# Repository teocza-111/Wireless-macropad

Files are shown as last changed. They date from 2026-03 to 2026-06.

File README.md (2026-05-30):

# Wireless-macropad
It's a basic 3x3 keyboard with bluetooth connectivity and a rotary encoder built on ZMK firmware.
## Quick note for forge reviewers:
This project was fully funded by stasis I'm moving this here since I plan to make my future projects on forge 
## It features a(n):
- nrf52840 microcontroller
- Seeed 106990290 lipo charger
- EC11E Rotary Encoder w/ switch
- Li-Po Battery 4000mah
### Why?
I like simracing but i needed some extra keybinds so i made my first vesion of this project but it was annoying that there was an extra cable on my desk so now im making it wireless.
# Media
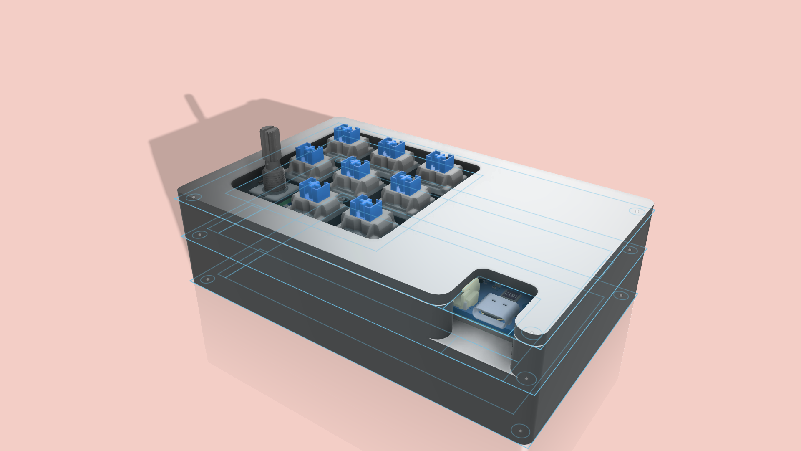
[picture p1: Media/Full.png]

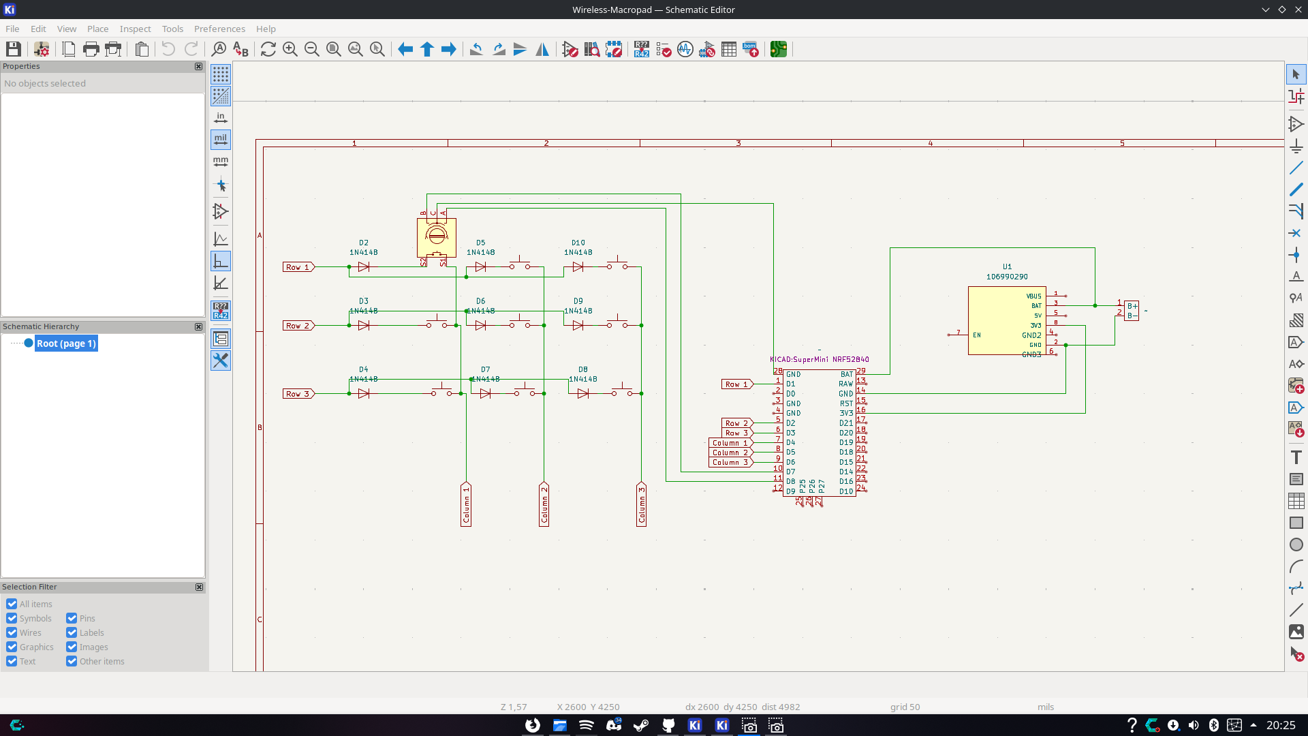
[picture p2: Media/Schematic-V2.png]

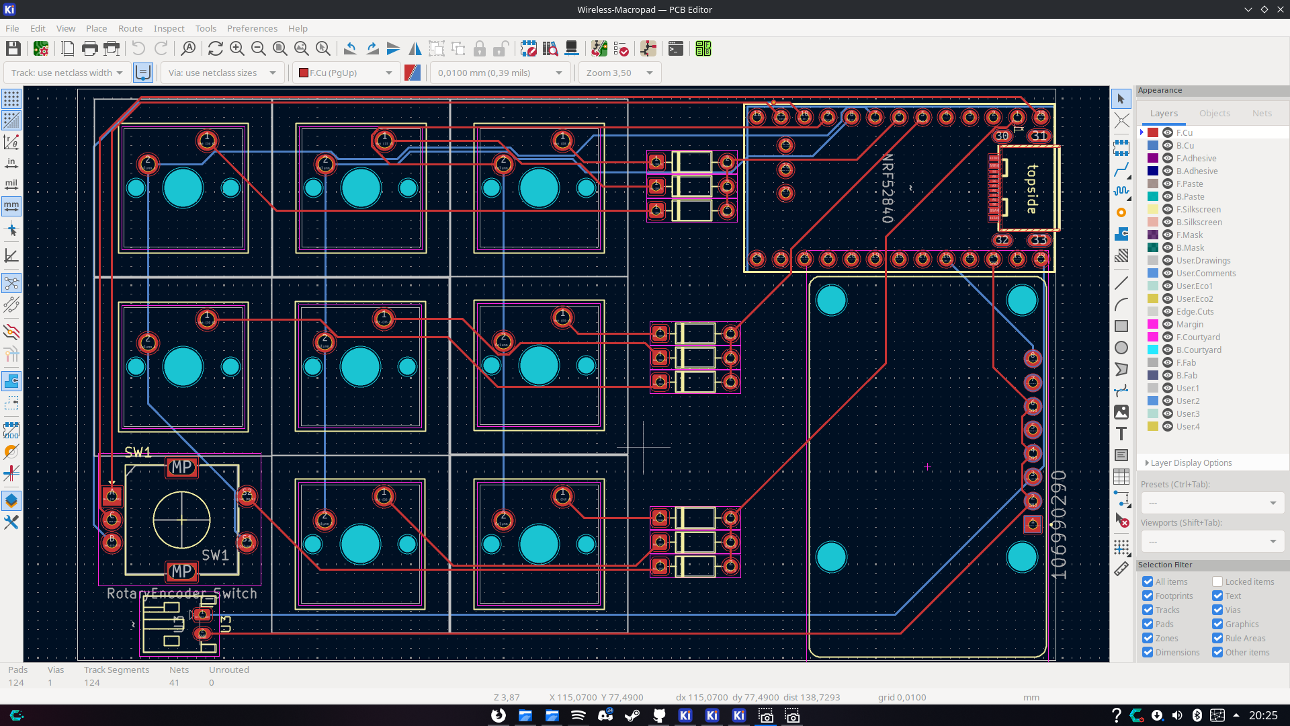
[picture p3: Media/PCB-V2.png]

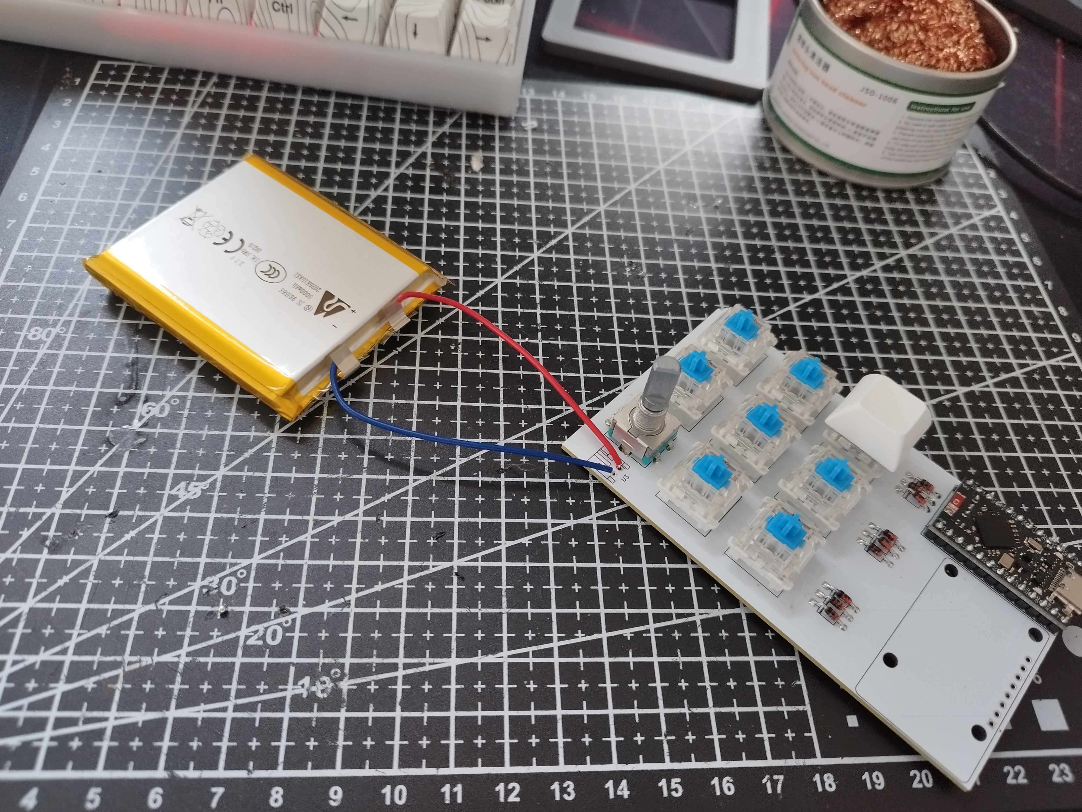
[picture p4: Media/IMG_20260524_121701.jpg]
build

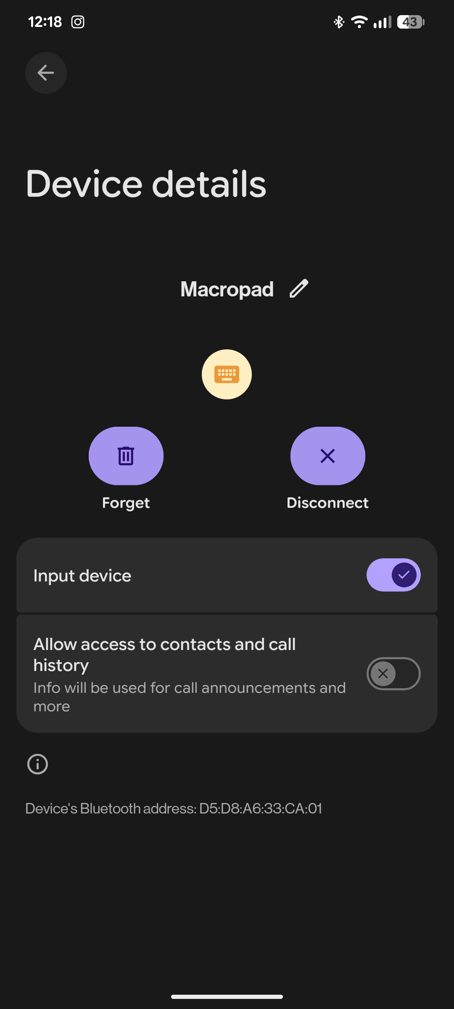
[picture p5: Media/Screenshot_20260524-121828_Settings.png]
build2

# BoM
|Part Name |Qty.|Cost (per part/batch) in PLN|Cost (total) in PLN|Link |
|---|----|---|---|---|
|nrf52840 microcontroller |1 |15,89zł |14,79zł |https://pl.aliexpress.com/item/1005009516681283.html|
|Seeed 106990290 (lipo charger) |1 |29,29zł |29,29zł |https://pl.aliexpress.com/item/4000572310671.html |
|1N4148 Diodes |9 |4,79zł |4,79zł |https://pl.aliexpress.com/item/1005006245109375.html|
|Cherry MX switches |8 |9,07zł |9,07zł |https://pl.aliexpress.com/item/1005010462521108.html|
|EC11E Rotary Encoder w/ switch |1 |12,59zł |12,59zł |https://pl.aliexpress.com/item/1005005983134515.html|
|Li-Po Battery 5000mah |1 |30,69zł |30,69zł |https://pl.aliexpress.com/item/1005010088690191.html|
|JST PH 2.0mm connector |1 |6,03zł |6,03zł |https://pl.aliexpress.com/item/1005004955655144.html|
|Keycaps |8 |15,50zł |15,50zł |https://pl.aliexpress.com/item/1005002906017844.html|
|Neodymium magnets 4x2mm |16  |9,06zł |9,06zł |https://pl.aliexpress.com/item/1005010075244557.html|
|ALL PRICES IN PLN!!! | |Total cost is → |131,81zł | |
|Note: | | | | |
|Things that are usually bought in bulk (diodes switches etc.) come in packs of for example 50 even if you only need 5| | | | |

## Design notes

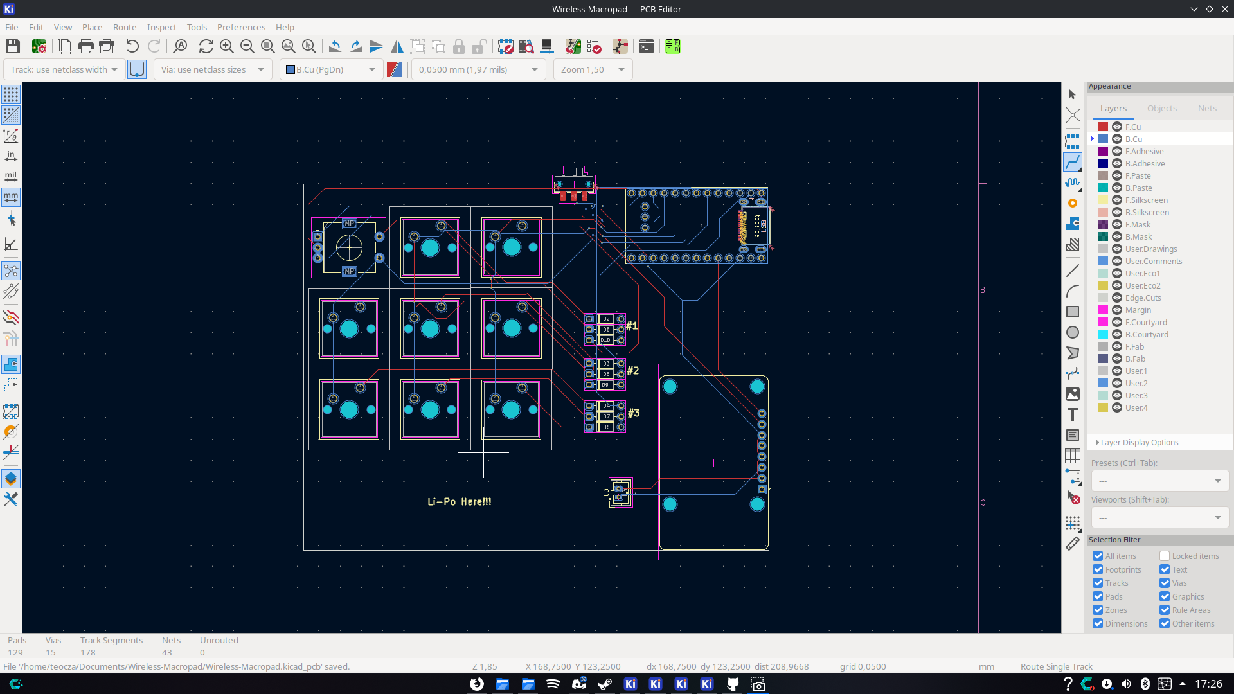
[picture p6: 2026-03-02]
Media/Screenshot_2.png

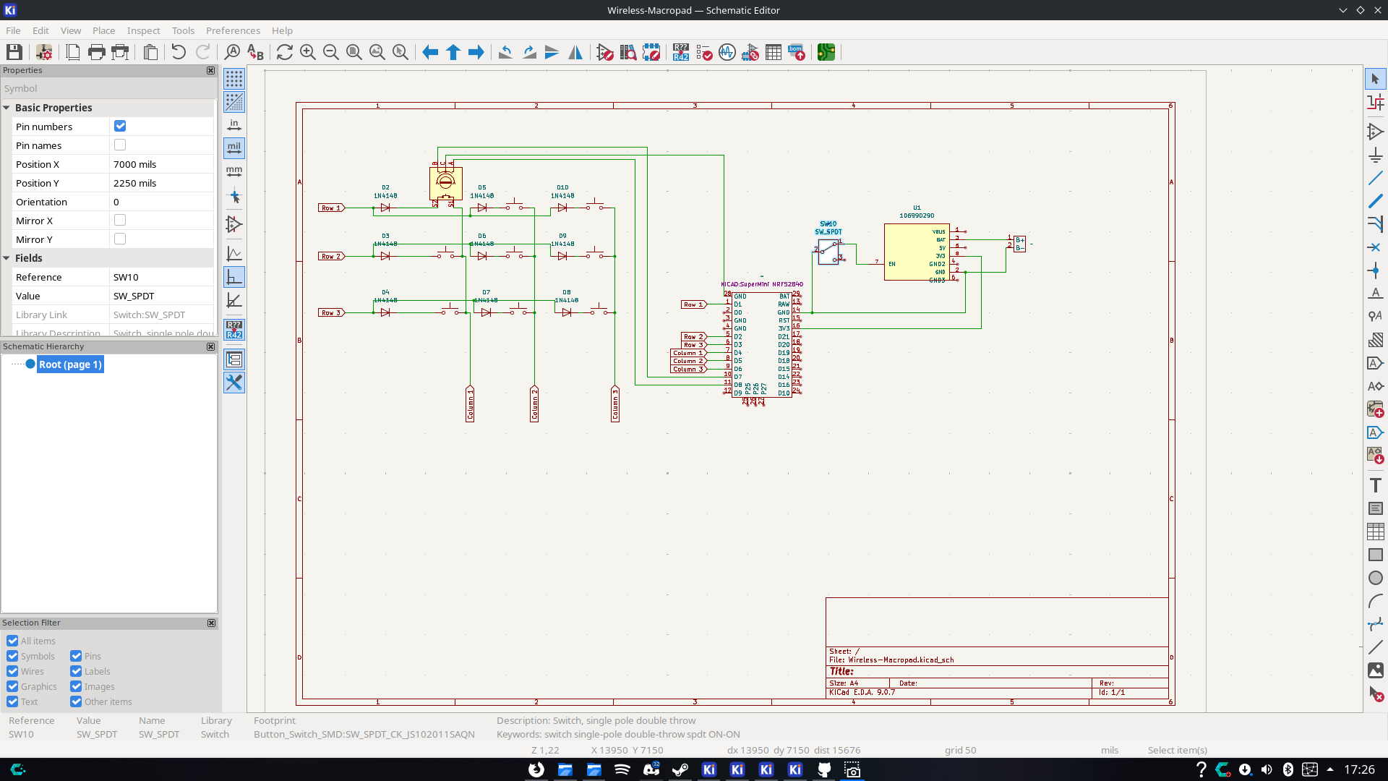
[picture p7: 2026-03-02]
Media/Screenshot_1.png

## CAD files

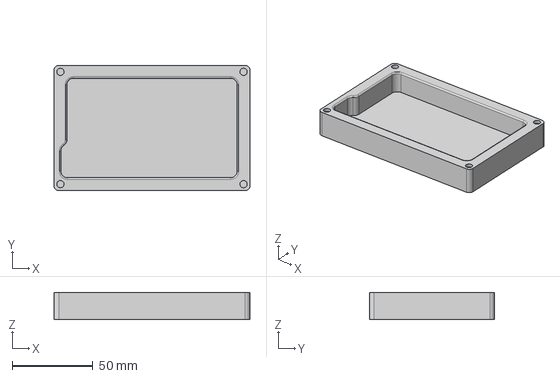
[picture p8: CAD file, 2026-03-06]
Case/BatteryCase.step
121.5 x 77.6 x 17.0 mm

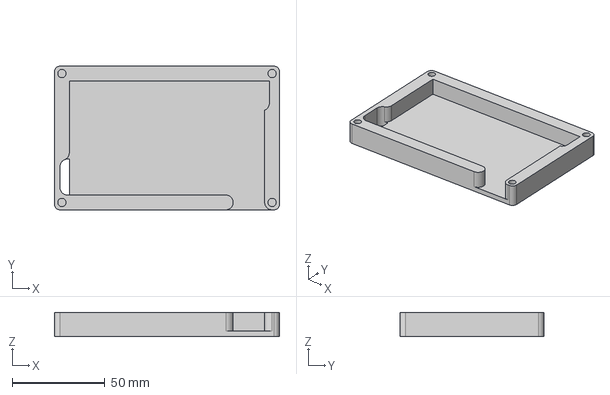
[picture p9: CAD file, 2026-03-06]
Case/PCBCase.step
121.5 x 77.6 x 13.0 mm

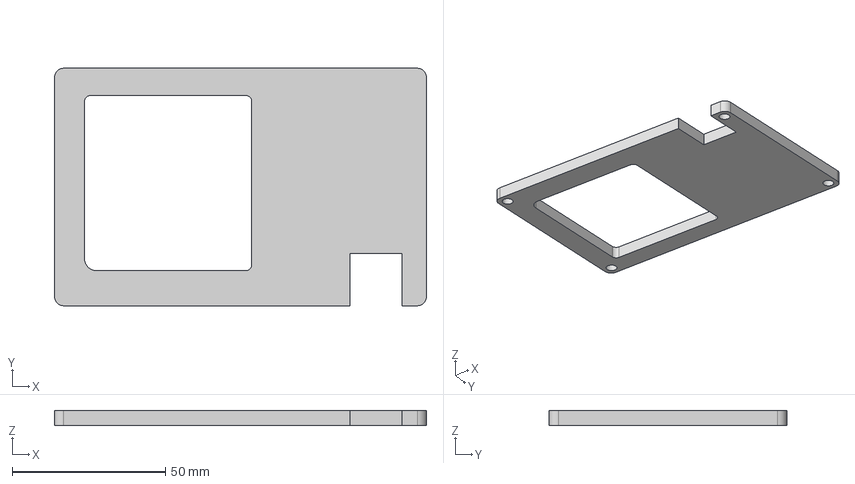
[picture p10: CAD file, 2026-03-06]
Case/TopCase.step
121.5 x 77.6 x 5.00 mm

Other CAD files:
Case/BatteryCase.stl
Case/PCBCase.stl
Case/TopCase.stl

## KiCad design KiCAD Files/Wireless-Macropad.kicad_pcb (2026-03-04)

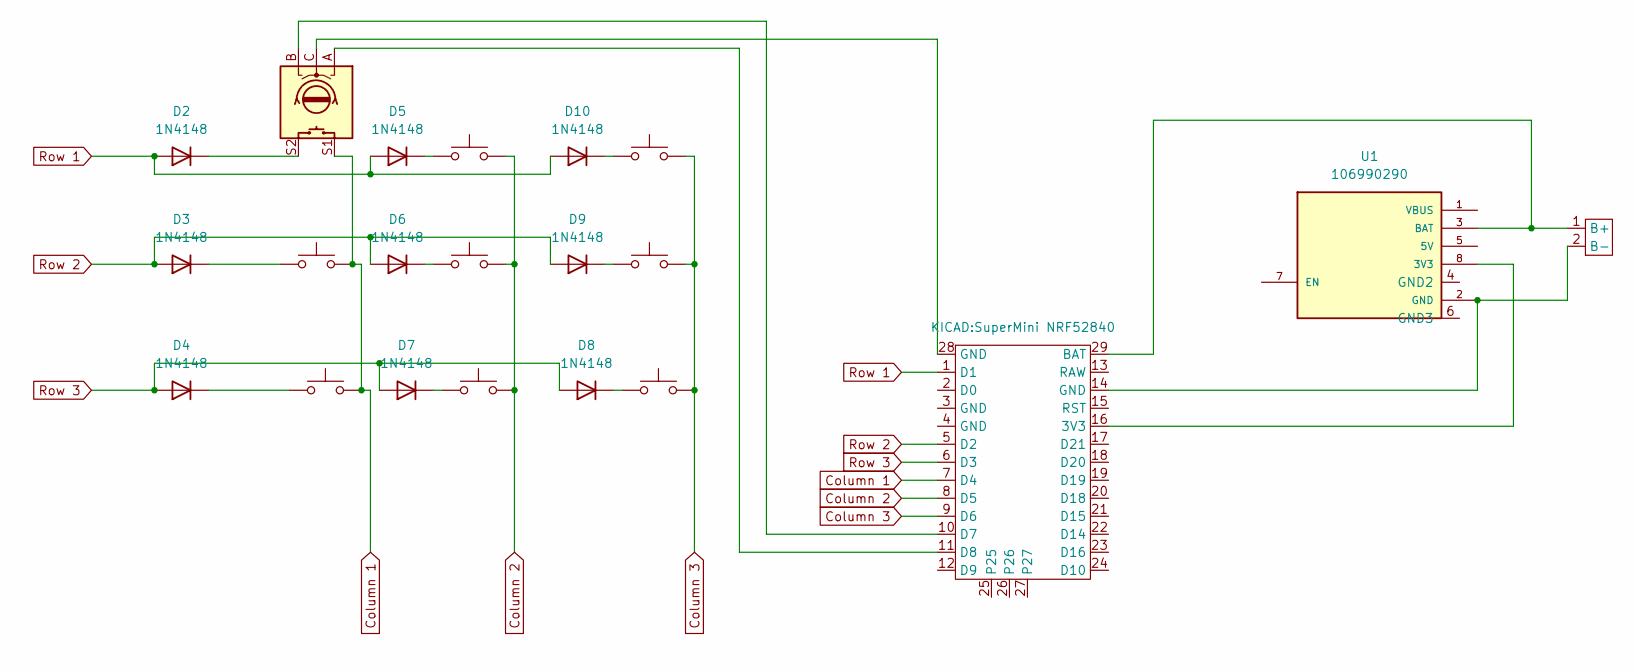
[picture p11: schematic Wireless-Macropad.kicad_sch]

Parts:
D2, D3, D4, D5, D6, D7, D8, D9, D10: 1N4148; D_DO-35_SOD27_P7.62mm_Horizontal
SW1: RotaryEncoder_Switch; RotaryEncoder_Alps_EC11E-Switch_Vertical_H20mm
SW2, SW3, SW4, SW5, SW6, SW7, SW8, SW9: SW_Push; SW_Cherry_MX_1.00u_PCB
U1: 106990290; MODULE_106990290; PARTREV NA
U2: SuperMini NRF52840
U3: JST_PH_S2B-PH-K_1x02_P2.00mm_Horizontal

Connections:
Column 1: SW1.S1, SW4.2, SW7.2, U2.7 (D4)
Column 2: SW2.2, SW5.2, SW8.2, U2.8 (D5)
Column 3: SW3.2, SW6.2, SW9.2, U2.9 (D6)
GND: U1.2 (GND), U1.4 (GND), U1.6 (GND), U2.14 (GND), U3.2 (B-)
unnamed: D2.1 (K), SW1.S2
unnamed: D3.1 (K), SW4.1
unnamed: D4.1 (K), SW7.1
unnamed: D5.1 (K), SW2.1
unnamed: D6.1 (K), SW5.1
unnamed: D7.1 (K), SW8.1
unnamed: D8.1 (K), SW9.1
unnamed: D9.1 (K), SW6.1
unnamed: D10.1 (K), SW3.1
unnamed: SW1.C, U2.28 (GND)
unnamed: U1.8 (3V3), U2.16 (3V3)
unnamed: U1.3 (BAT), U2.29 (BAT), U3.1 (B+)
unnamed: SW1.B, U2.10 (D7)
unnamed: SW1.A, U2.11 (D8)
Row 1: D2.2 (A), D5.2 (A), D10.2 (A), U2.1 (D1)
Row 2: D3.2 (A), D6.2 (A), D9.2 (A), U2.5 (D2)
Row 3: D4.2 (A), D7.2 (A), D8.2 (A), U2.6 (D3)

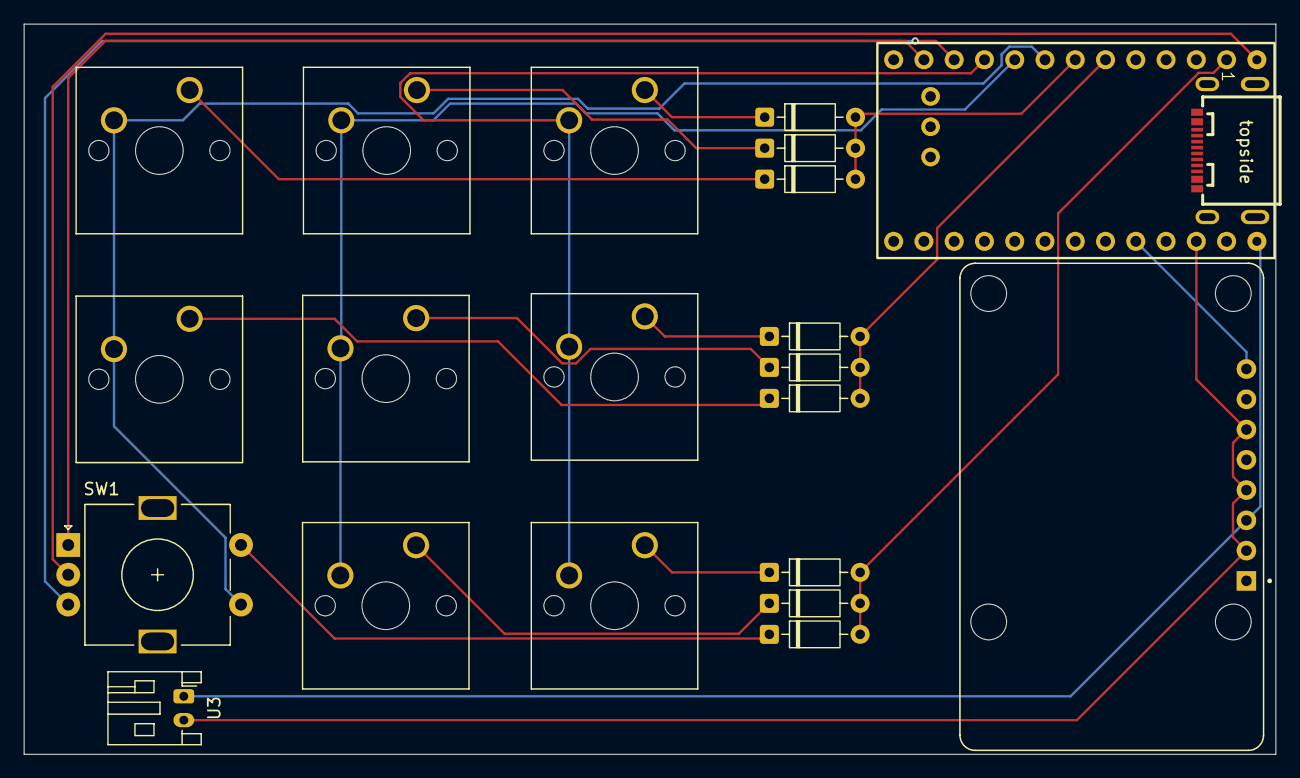
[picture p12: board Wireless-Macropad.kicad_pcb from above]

Board: 2 copper layers, 105.1 x 61.3 mm, 21 parts (0 on the bottom side), 21 nets.

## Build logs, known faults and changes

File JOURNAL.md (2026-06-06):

---
title: "A nicer macropad"
author: "teocza"
description: "A wireless 3x3 keyboard with a rotary encoder"
created_at: "2026-03-02"
---

# 3/2/2026 4 PM - Created the schematic, routed the pcb etc.

_Time spent: 10h_

I got bored with my older design so i making this one wireless,
I'm using an nrf52840-based microcontroller for bluetooth connectivity, a 5000mah battery and the same 3x3 layout.
So basically i made the schematic, it's a simple key matrix nothing much
It has a rotary encoder that also serves a purpose as one of the key is the matrix

I made the pcb, idk how will the battery fit here but ill think abt it later

# 3/4/2026 8 PM - Redesigned the PCB and made thefirmware.

_Time spent: 4.5h_

Figured out the battery problem, it will sit below the whole pcb in a seperate "tray", this mean that the case will have 3 parts. And the best way imo to hold this togheter is magnets.
So i redesigned the PCB, bc i dont have to make any space for the battery i was able to make this much smaller.
I removed the power switch and added a JST-PH female port to connect the battery later (god im repeating batter so much wth)
The rest is the same
PCB-V2
Schematic-V2

# 3/6/2026 5 PM - Finished the BoM and made the case

_Time spent: 4h_

Modeled the whole case, again it's a 3 part case that will be held togheter with neodynium magnets, the bottom part hold the battery, the middle holds the pcb with switches and encoder.
i decided to use a 4000mah battery, ill try to find the biggest one that can fit inside that case for the best lifetime but this is the best i have for now.
Also made the whole bill of materials with links prices etc.

Full

# 5/21/2026 8 PM - Build D1 - Soldering and first firmware test (debugging)

_Time spent: 3h_

Most of the stuff arrived, time to assemble
so i soldered the microcontroller switches the encoder and diodes onto the pcb.

Uploaded the firmware which didnt go well.
I got a ton of ghosting, keys being pressed all the time (including encoder). I triple checked every single thing, no shorts, no faulty components. Diode type in firmware is correct, i tried changing it and then it just stopped receiveing an info from the switches, only the encoder worked.
After changing the config and recompiling many times i wasnt able to find what exactly is wrong, ill try to find out later.
Meanwhile the case is getting printed, the magnets should arrive tommorow.

# 5/24/2026 10 AM - Build D2 and 3 - Finished fixing the firmware and assembled everything

_Time spent: 3h_

Turned out that i had the GPIO_PULL_UP flag on the wrong pins, fixed that and also added a GPIO_PULL_DOWN flag on the rest for stable output.

I order a 5000mAh battery with a jst-ph 2mm connector from aliexpress but recieved 2 of them without a connector
unnamed
Also i just realised that the board has battery charging capabilites built into itself so i ditched the charging module to keep it simple.
I will eventually order a male jst-ph port to proparly connect it onto the pcb, but i just dont want to wait 2 weeks for one.



That should be all, next time im ordering something from aliexpress ill add a jst port

# 6/6/2026 10PM - Quick readme update

_Time spent: 0.5h_

Stasis generated the journal in reverse, that made it quite confusing to read, also the images were inserted twice into every journal entry for some reason.
Rewrote the thing so it better explains what progress i've made every day, hope this is enough
Zrzut ekranu (146)

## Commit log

2026-03-02 Added a BoM and finished designing my pcb.
    [BoM - BoM.csv, Wireless-Macropad.kicad_pcb, Wireless-Macropad.kicad_sch]
2026-03-04 Updated my PCB and generated my gerber file
    [Wireless-Macropad.kicad_pcb, Wireless-Macropad.kicad_sch]
2026-03-04 Added firmware and updated design
    Firmware made using ZMK, also updated BoM to match current parts
    [BoM - BoM.csv]
2026-03-06 Made the case
    [BatteryCase.step, BatteryCase.stl, PCBCase.step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]
2026-03-06 Updated BoM.csv
    [BoM - BoM.csv]
2026-03-06 Update Li-Po Battery capacity in README
2026-03-21 Update BoM with new parts and prices
    [BoM - BoM.csv]
2026-03-21 Updated BoM with correct links
    [BoM - BoM.csv, BoM.csv]
2026-04-27 Add Bill of Materials section to README
    Added a Bill of Materials (BoM) section with details on parts, quantities, costs, and links.
2026-04-27 Added teh gerber file
